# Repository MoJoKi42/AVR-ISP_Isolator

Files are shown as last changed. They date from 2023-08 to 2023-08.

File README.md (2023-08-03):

# AVR-ISP_Isolator
Isolator Board for AVR ISP/SPI Programmers

Works well with the **AVR Dragon** and eBay **USB AVRISP** clones. With the buttons (relays) it's possible to disconnect the data and power lines from the external circuit. This is very useful if the SPI pins have multiple purposes. The external voltage can vary from 3 to 5V. (The large THT resistor is already designed into the kicad project. This resistor was necessary because the P-Ch. FET has a higher leakage than expected)

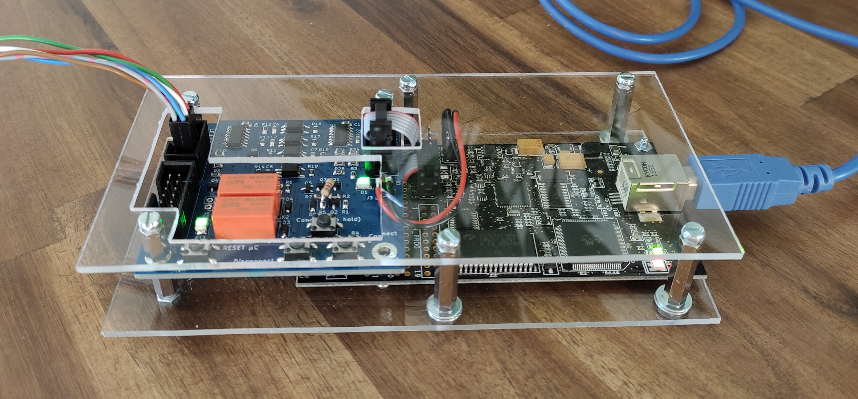
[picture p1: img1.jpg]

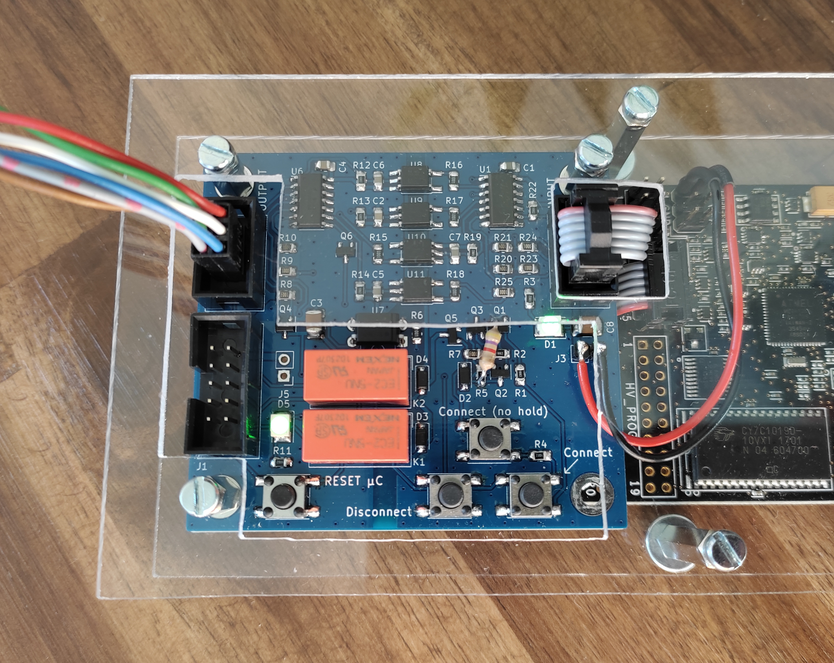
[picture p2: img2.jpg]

Isolator with AVR Dragon in a self-built housing

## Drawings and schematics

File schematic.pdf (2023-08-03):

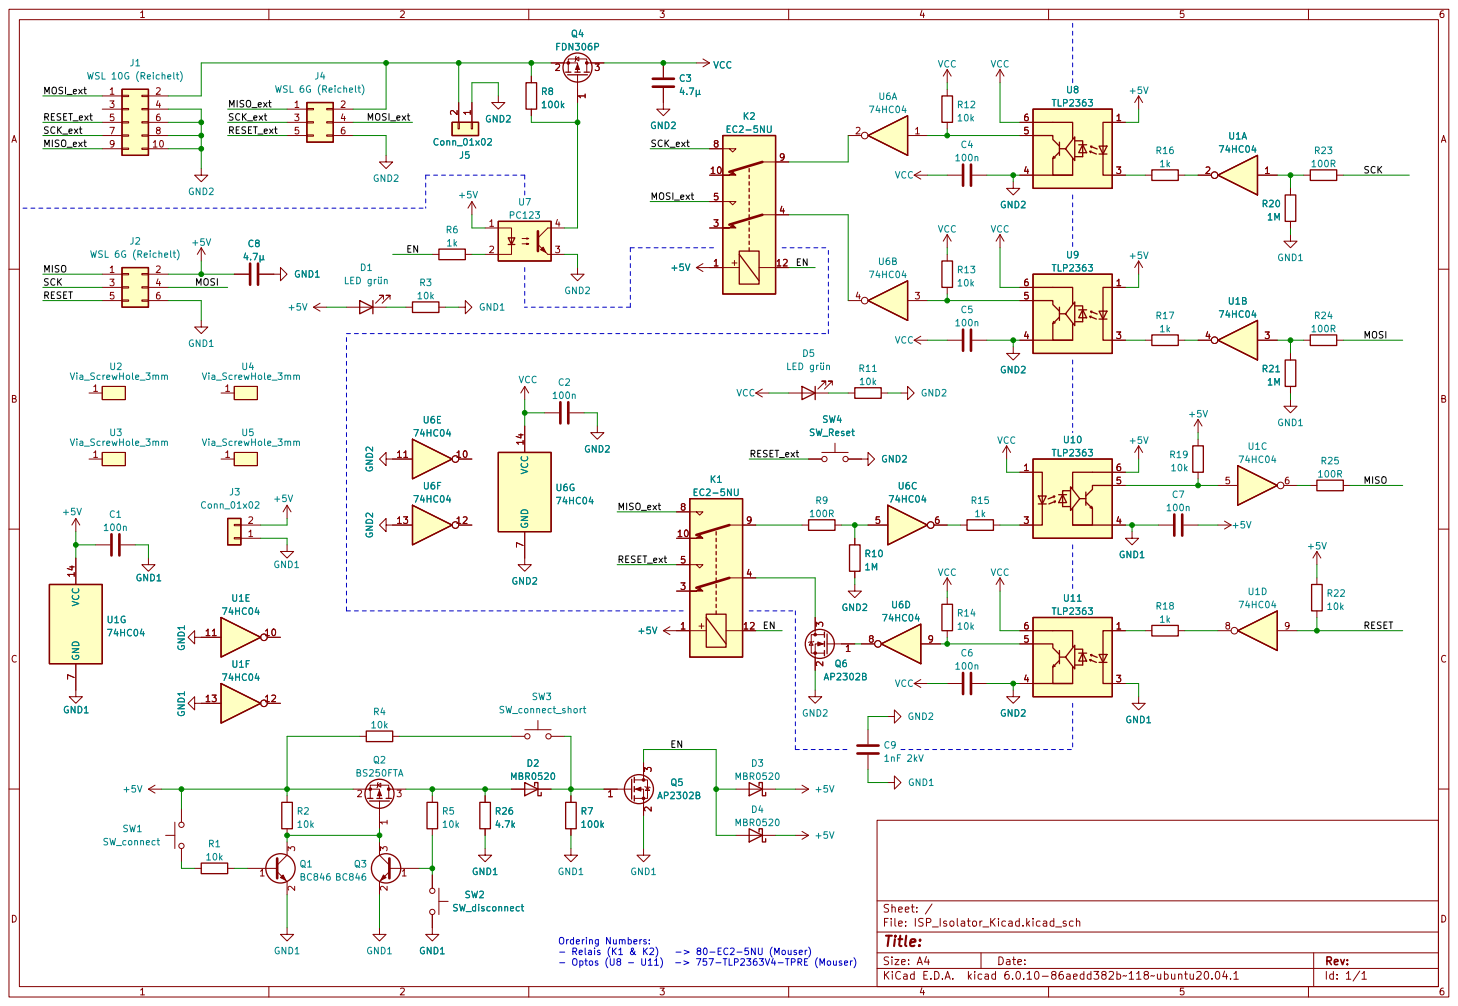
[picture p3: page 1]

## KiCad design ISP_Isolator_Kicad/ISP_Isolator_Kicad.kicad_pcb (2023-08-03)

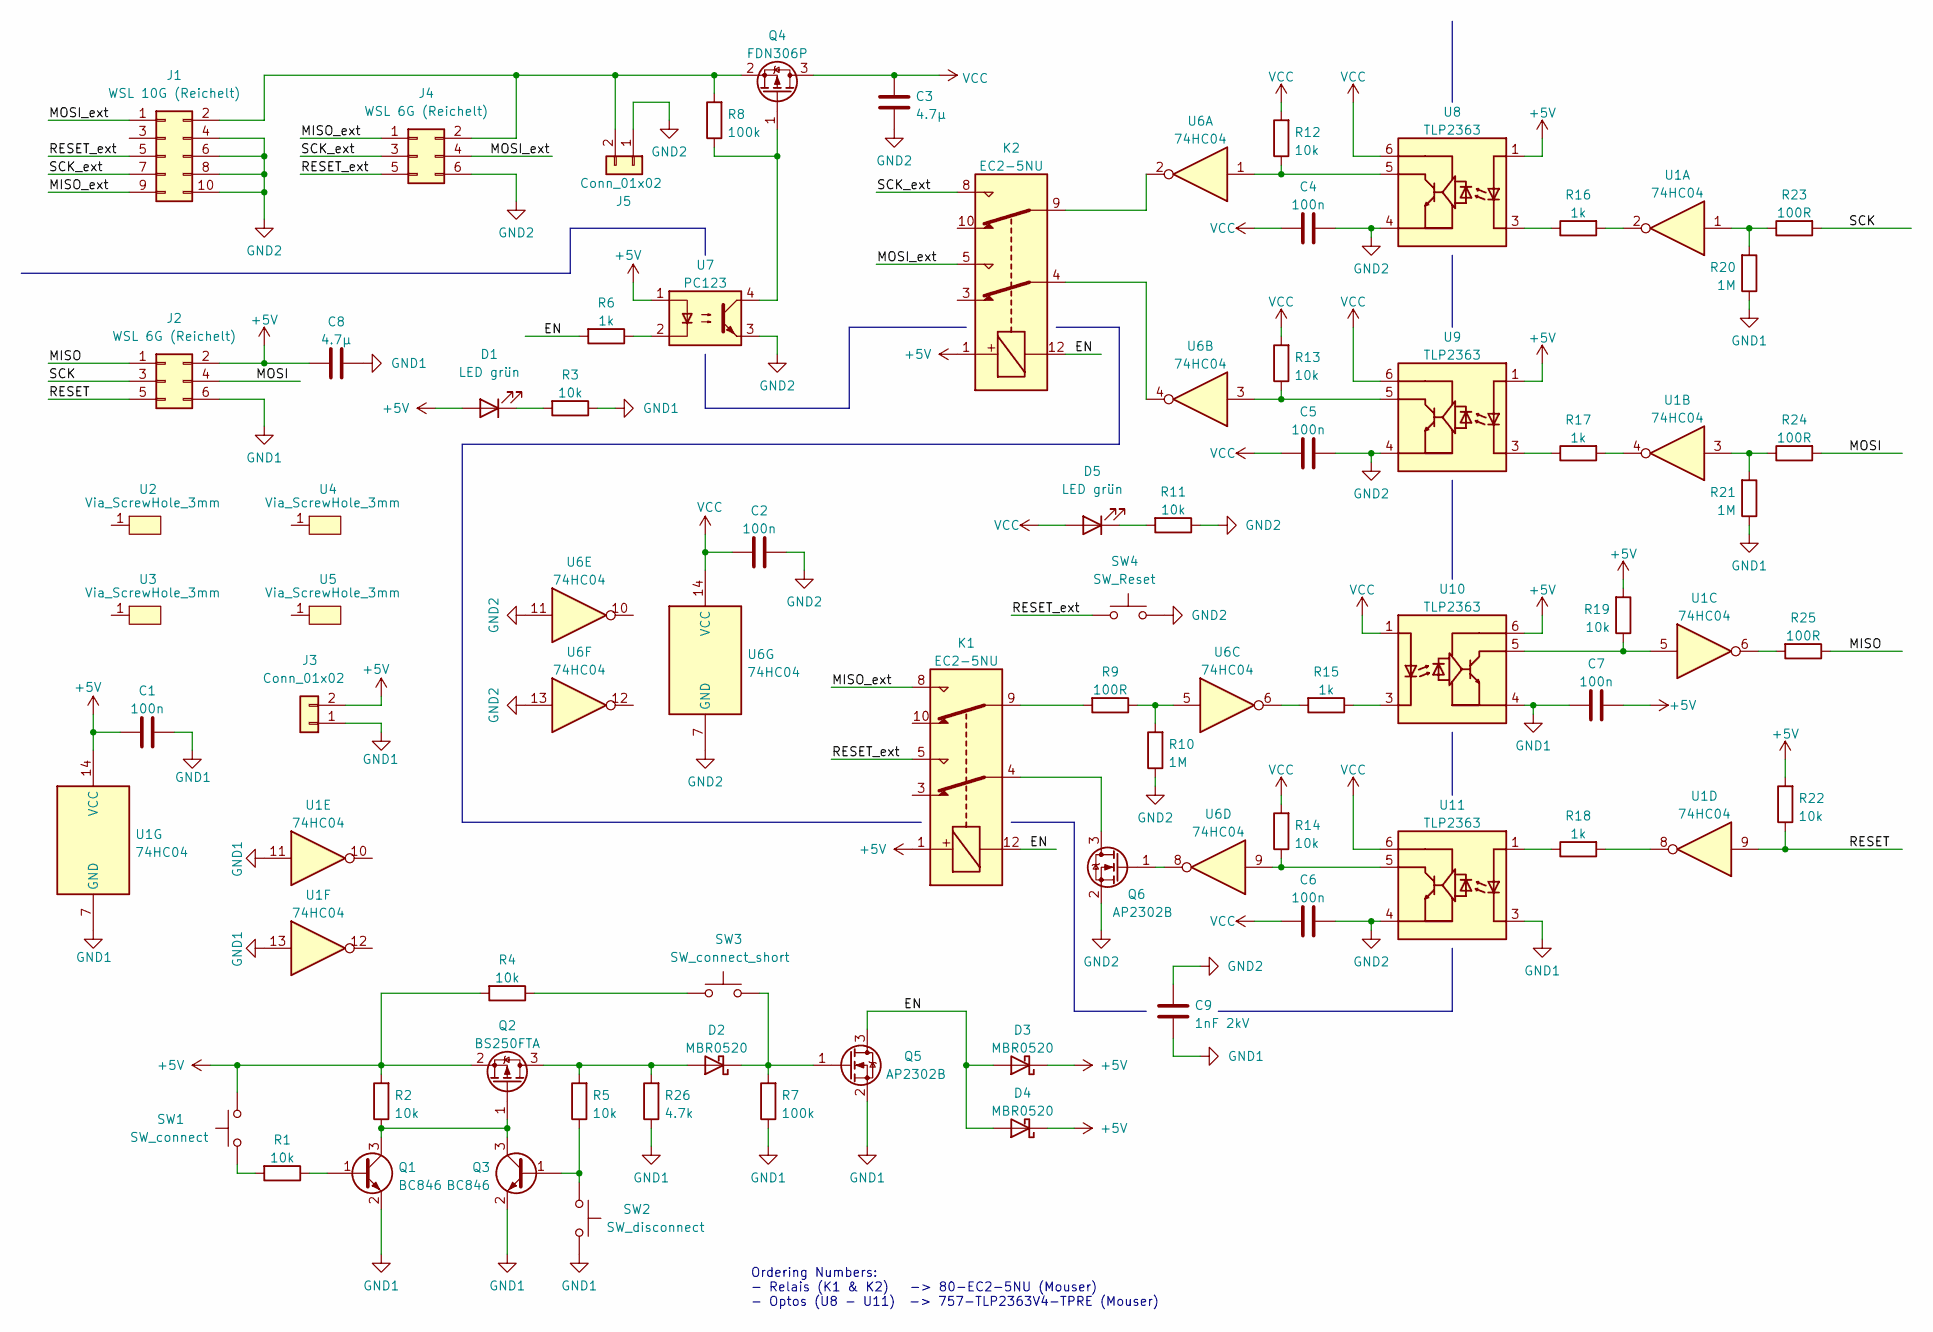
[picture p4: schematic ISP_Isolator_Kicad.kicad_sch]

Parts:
C1, C2, C4, C5, C6, C7: 100n; C_0805_2012Metric_Pad1.18x1.45mm_HandSolder
C3, C8: 4.7µ; C_1210_3225Metric_Pad1.33x2.70mm_HandSolder
C9: 1nF 2kV; C_1206_3216Metric_Pad1.33x1.80mm_HandSolder
D1, D5: LED grün; LED_PLCC-2_3.4x3.0mm_AK
D2, D3, D4: MBR0520; D_SOD-123
J1: WSL 10G (Reichelt); IDC-Header_2x05_P2.54mm_Vertical
J2, J4: WSL 6G (Reichelt); IDC-Header_2x03_P2.54mm_Vertical
J3, J5: Conn_01x02; PinHeader_1x02_P2.54mm_Vertical
K1, K2: EC2-5NU; Relay_DPDT_Kemet_EC2
Q1, Q3: BC846; SOT-23
Q2: BS250FTA; SOT-23
Q4: FDN306P; SOT-23
Q5, Q6: AP2302B; SOT-23
R1, R2, R3, R4, R5, R11, R12, R13, R14, R19, R22: 10k; R_0805_2012Metric_Pad1.20x1.40mm_HandSolder
R6, R15, R16, R17, R18: 1k; R_0805_2012Metric_Pad1.20x1.40mm_HandSolder
R7, R8: 100k; R_0805_2012Metric_Pad1.20x1.40mm_HandSolder
R9, R23, R24, R25: 100R; R_0805_2012Metric_Pad1.20x1.40mm_HandSolder
R10, R20, R21: 1M; R_0805_2012Metric_Pad1.20x1.40mm_HandSolder
R26: 4.7k; R_0805_2012Metric_Pad1.20x1.40mm_HandSolder
SW1: SW_connect; SW_Push_1P1T_NO_6x6mm_H9.5mm
SW2: SW_disconnect; SW_Push_1P1T_NO_6x6mm_H9.5mm
SW3: SW_connect_short; SW_Push_1P1T_NO_6x6mm_H9.5mm
SW4: SW_Reset; SW_Push_1P1T_NO_6x6mm_H9.5mm
U1, U6: 74HC04; SO-14_3.9x8.65mm_P1.27mm
U2, U3, U4, U5: Via_ScrewHole_3mm
U7: PC123; DIP-4_W7.62mm
U8, U9, U10, U11: TLP2363; SO-5_4.4x3.6mm_P1.27mm

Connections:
+5V: C1.1, C7.1, C8.1, D1.2 (A), D3.1 (K), D4.1 (K), J2.2, J3.2, K1.1, K2.1, Q2.2 (S), R2.2, R4.2, R19.2, R22.2, SW1.1, U1.14 (VCC), U7.1, U8.1, U9.1, U10.6
/EN: D3.2 (A), D4.2 (A), K1.12, K2.12, Q5.3 (D), R6.2
/MISO: J2.1, R25.1
/MISO_ext: J1.9, J4.1, K1.8
/MOSI: J2.4, R24.2
/MOSI_ext: J1.1, J4.4, K2.5
/RESET: J2.5, R22.1, U1.9
/RESET_ext: J1.5, J4.5, K1.5, SW4.2
/SCK: J2.3, R23.2
/SCK_ext: J1.7, J4.3, K2.8
GND1: C1.2, C7.2, C8.2, C9.2, J2.6, J3.1, Q1.2 (E), Q3.2 (E), Q5.2 (S), R3.1, R7.1, R20.1, R21.1, R26.1, SW2.2, U1.7 (GND), U1.11, U1.13, U10.4, U11.3
GND2: C2.2, C3.2, C4.2, C5.2, C6.2, C9.1, J1.4, J1.6, J1.8, J1.10, J4.6, J5.1, Q6.2 (S), R10.1, R11.1, SW4.1, U6.7 (GND), U6.11, U6.13, U7.3, U8.4, U9.4, U11.4
unnamed: D1.1 (K), R3.2
unnamed: D2.1 (K), Q5.1 (G), R7.2, SW3.1
unnamed: D5.1 (K), R11.2
unnamed: J1.2, J4.2, J5.2, Q4.2 (S), R8.2
unnamed: K1.4, Q6.3 (D)
unnamed: K1.9, R9.2
unnamed: K2.4, U6.4
unnamed: K2.9, U6.2
unnamed: Q1.1 (B), R1.1
unnamed: Q1.3 (C), Q2.1 (G), Q3.3 (C), R2.1
unnamed: D2.2 (A), Q2.3 (D), R5.2, R26.2
unnamed: Q3.1 (B), R5.1, SW2.1
unnamed: Q4.1 (G), R8.1, U7.4
unnamed: Q6.1 (G), U6.8
unnamed: R1.2, SW1.2
unnamed: R6.1, U7.2
unnamed: R9.1, R10.2, U6.5
unnamed: R12.1, U6.1, U8.5
unnamed: R13.1, U6.3, U9.5
unnamed: R14.1, U6.9, U11.5
unnamed: R15.1, U10.3
unnamed: R15.2, U6.6
unnamed: R16.1, U8.3
unnamed: R16.2, U1.2
unnamed: R17.1, U9.3
unnamed: R17.2, U1.4
unnamed: R18.1, U11.1
unnamed: R18.2, U1.8
unnamed: R19.1, U1.5, U10.5
unnamed: R20.2, R23.1, U1.1
unnamed: R21.2, R24.1, U1.3
unnamed: R25.2, U1.6
unnamed: R4.1, SW3.2
VCC: C2.1, C3.1, C4.1, C5.1, C6.1, D5.2 (A), Q4.3 (D), R12.2, R13.2, R14.2, U6.14 (VCC), U8.6, U9.6, U10.1, U11.6

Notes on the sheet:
Ordering Numbers: - Relais (K1 & K2) -> 80-EC2-5NU (Mouser) - Optos (U8 - U11) -> 757-TLP2363V4-TPRE (Mouser)

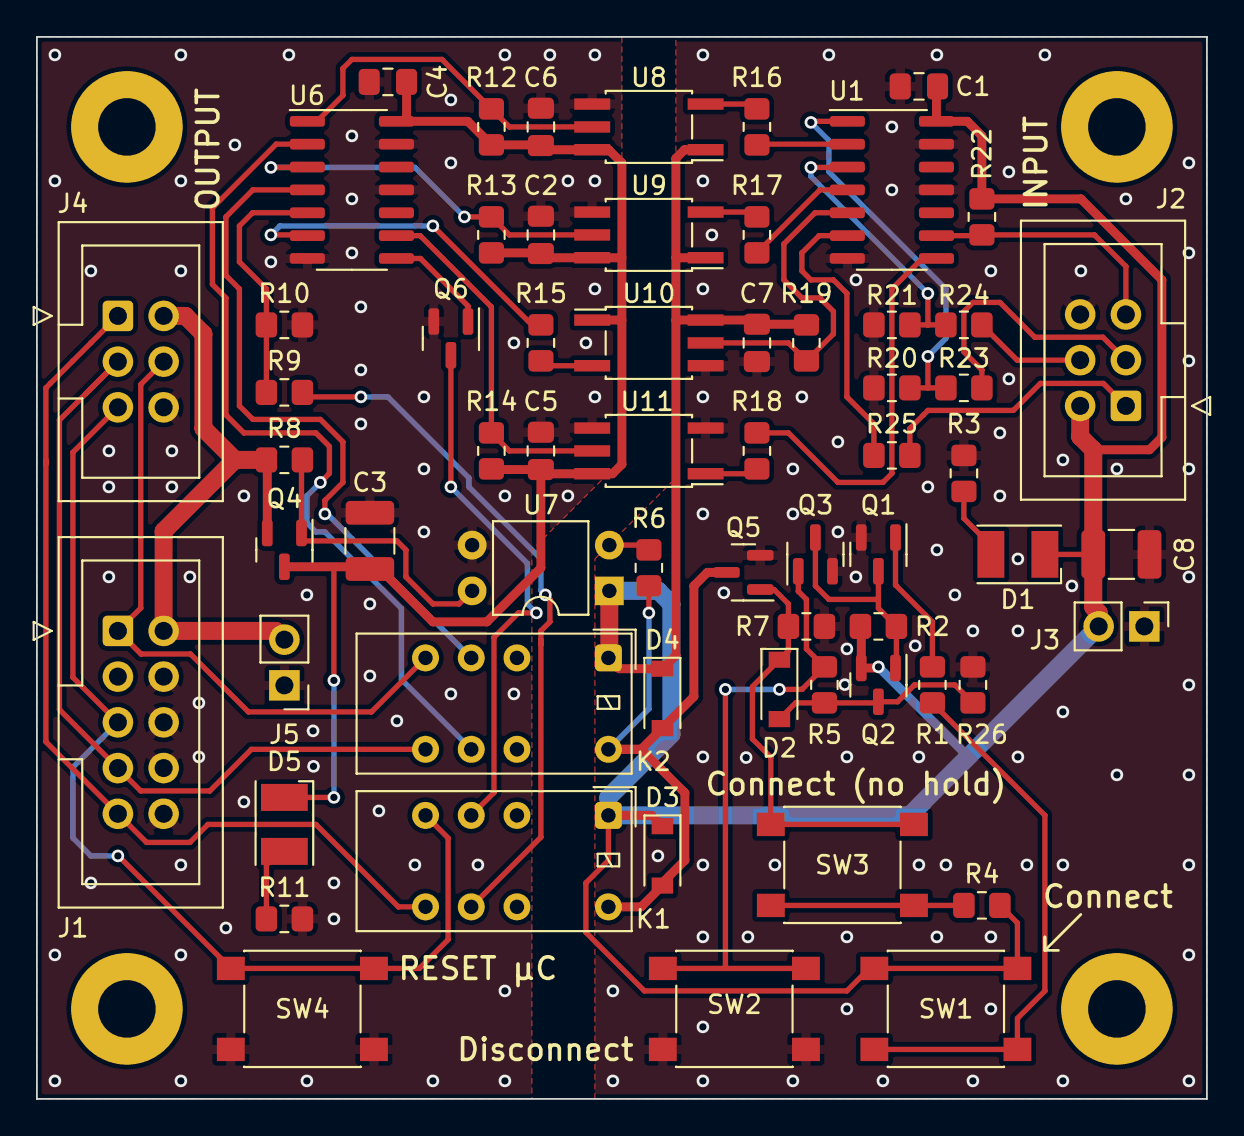
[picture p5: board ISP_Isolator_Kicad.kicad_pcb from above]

Board: 2 copper layers, 65.0 x 59.0 mm, 68 parts (1 on the bottom side), 46 nets.
